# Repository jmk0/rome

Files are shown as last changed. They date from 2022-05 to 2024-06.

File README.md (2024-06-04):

# ROME
RatOS Multi Extruder

A multi extruder feeder to direct extruder solution for RatOS

## Table of Content
- [Intro](#intro)
- [Installation](#installation)
    - [Raspberry](#raspberry)
    - [Moonraker](#moonraker)
    - [RatOS](#ratos)
- [Slicer](#slicer)
    - [G-code](#G-code)
    - [Native](#native)

## Printed Parts
  - [Filament Sensor](https://github.com/HelgeKeck/rome/tree/main/cad/stl/filament_sensors)
  - [MMU Splitter](https://github.com/HelgeKeck/rome/tree/main/cad/stl/mmu_splitter)
  - [Orbiter Mounts](https://github.com/HelgeKeck/rome/tree/main/cad/stl/orbiter_mounts)

# Intro

ROME is MUCH faster then any regular MMU, ERCF or similar setups. The whole filament unloading and loading process is multiple times faster, not only because ROME just has to park the filament behind the y-junction. In its native mode, ROME handles the loading and unloading process and skips the slicer controlled part of it. This process is highly optimized for a specific Hotend / Filament combination. No more configuration of cooling moves, skinnydip, ramming, .... 

You can even set the acceleration for the wipe tower, in combination with the slicer **max speed for the wipe tower** feature, you can speed up the process even more.

With its **Ooze Ex** feature, it lets you use the most oozing hotends on the markets, it still produces a clean wipe tower

Every MM loading and unloading setting in the slicer will be deactivated and replaced with a simple unload macro. 

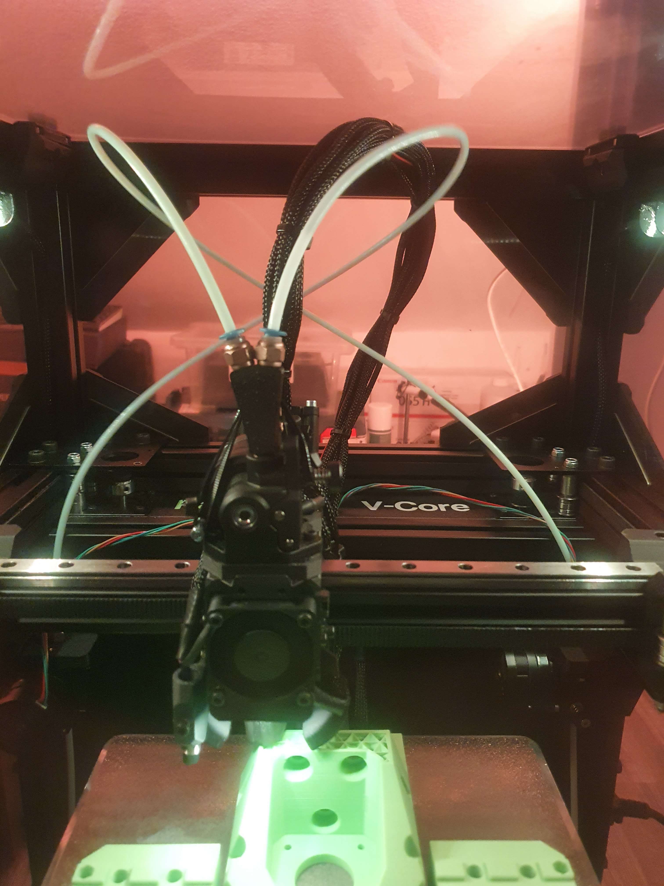
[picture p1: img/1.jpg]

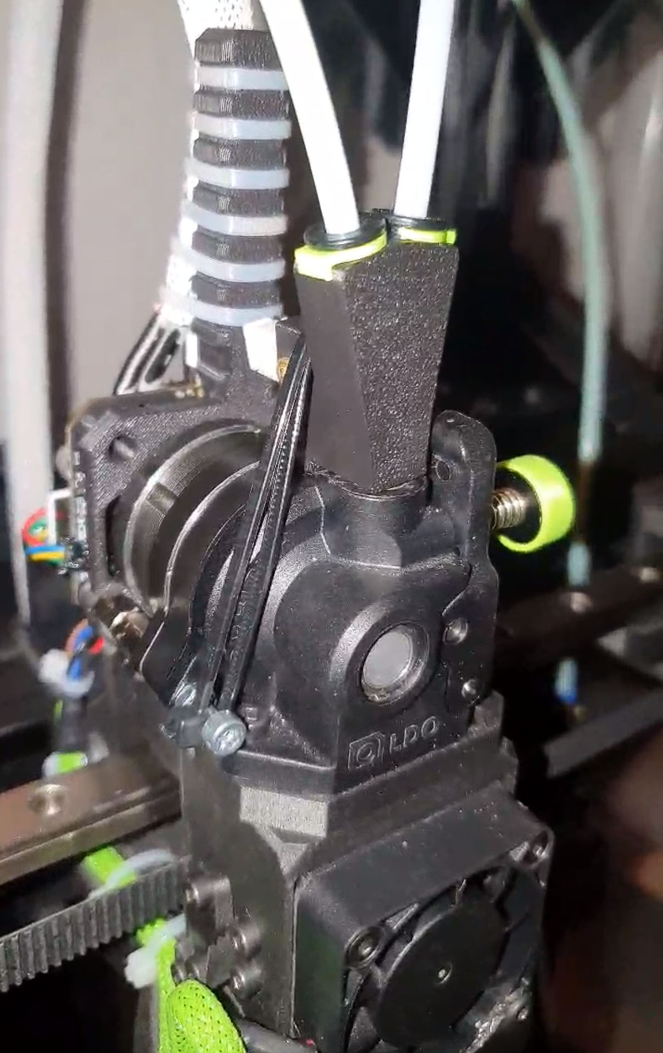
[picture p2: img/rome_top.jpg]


Wipe tower, printed with 300mm/s @ 25000 mm²/s acceleration on a Rapido UHF with Prusament PETG. 

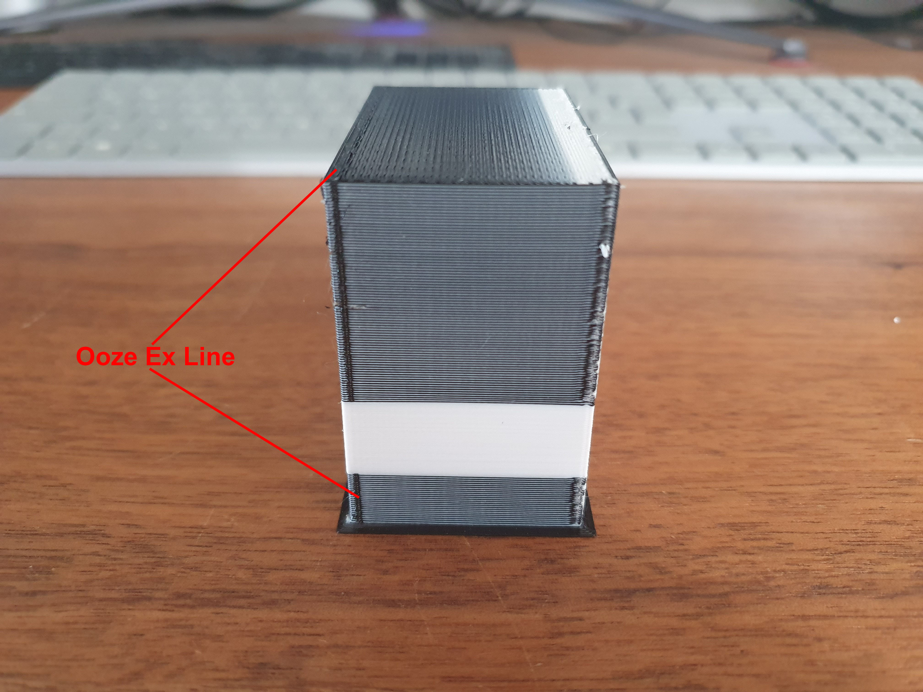
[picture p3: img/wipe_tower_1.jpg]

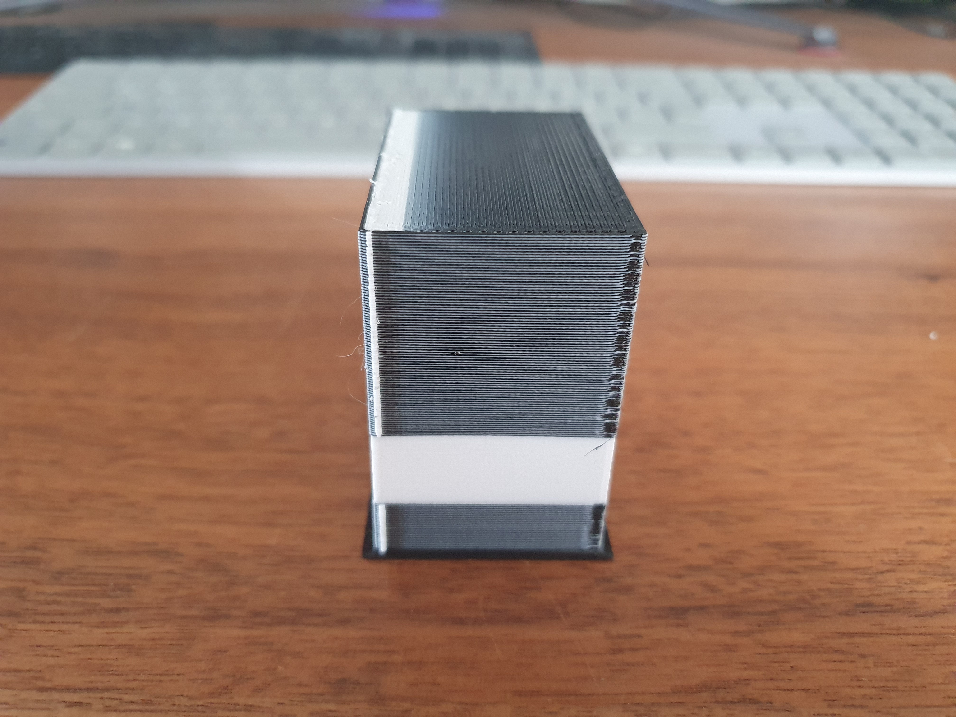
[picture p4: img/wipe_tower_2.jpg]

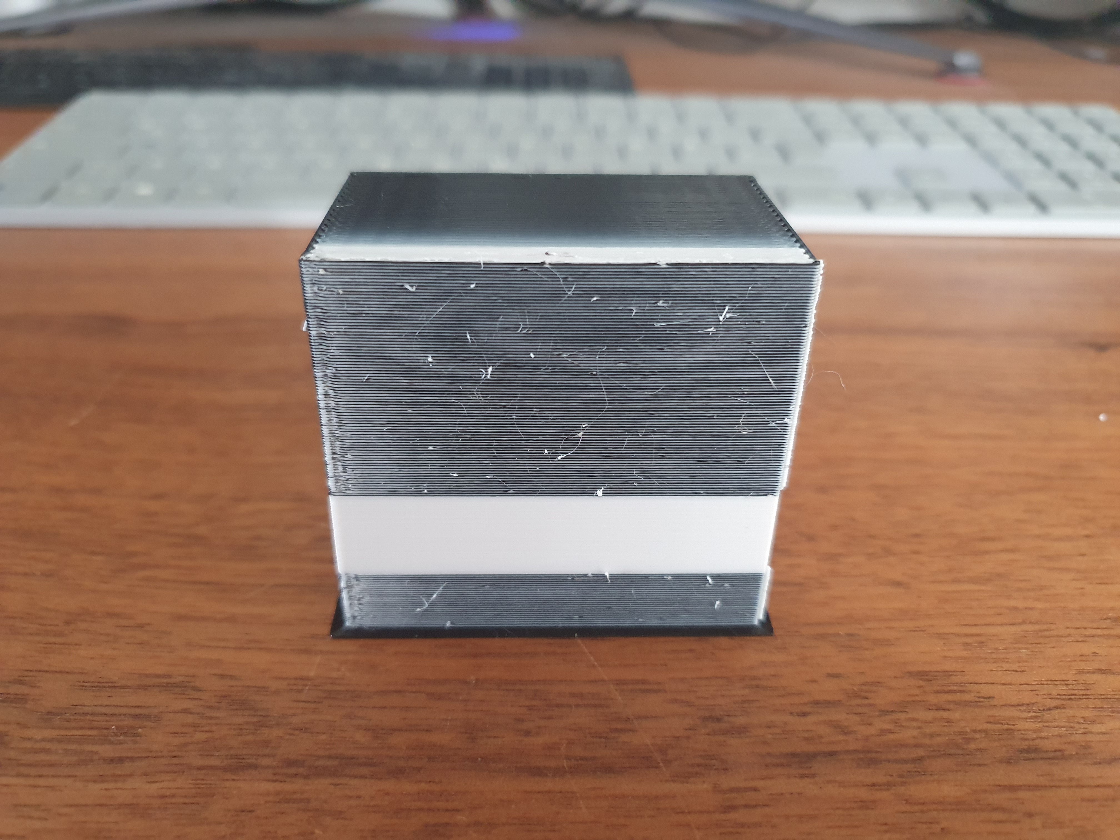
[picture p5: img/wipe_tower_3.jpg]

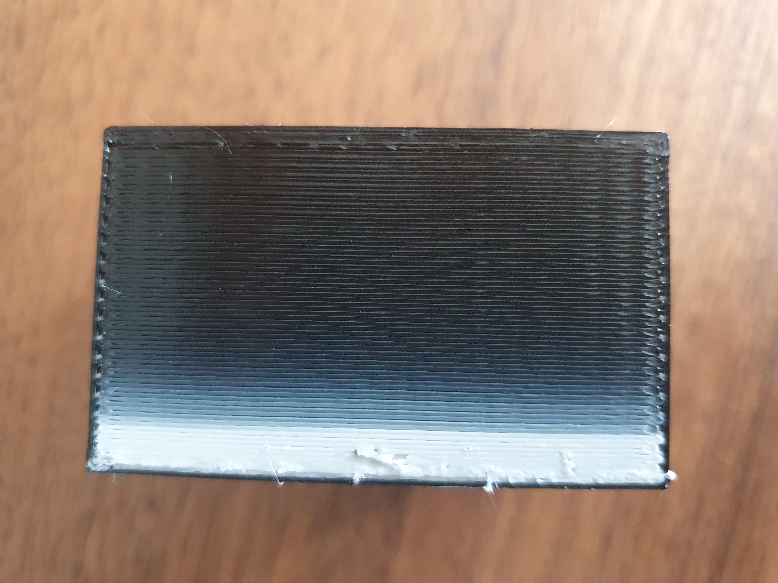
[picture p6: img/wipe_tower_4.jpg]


Examples 

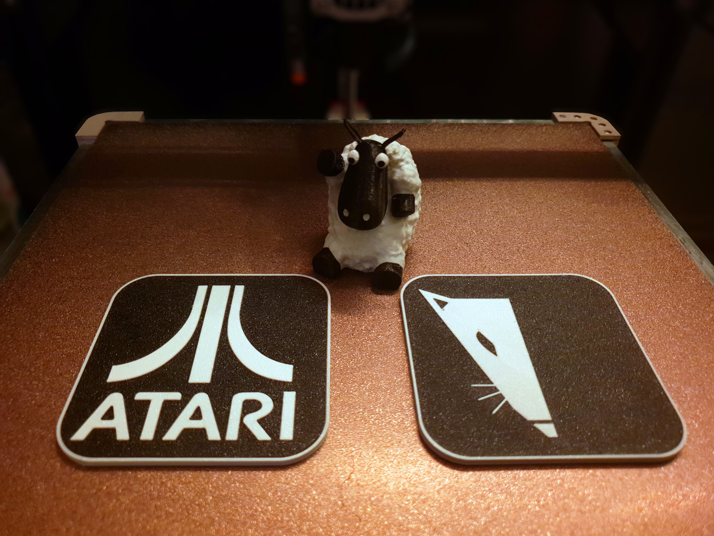
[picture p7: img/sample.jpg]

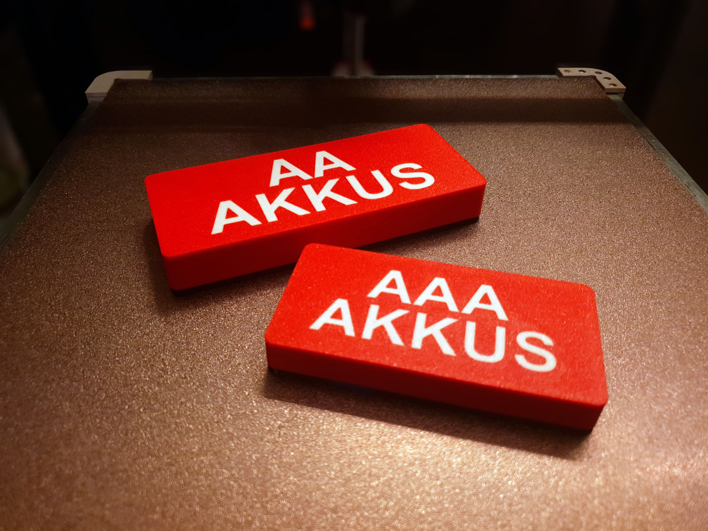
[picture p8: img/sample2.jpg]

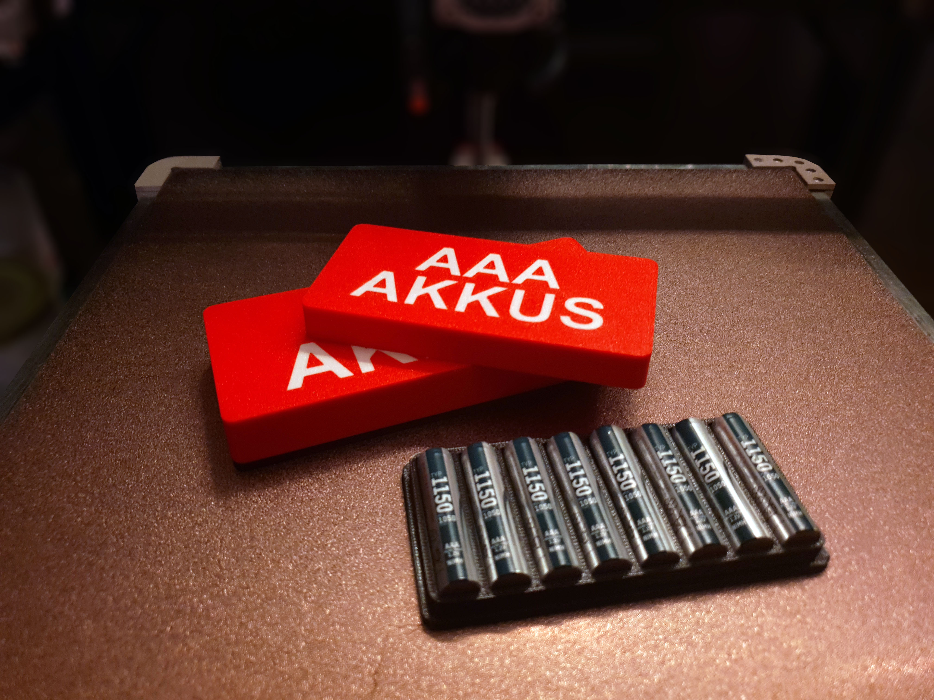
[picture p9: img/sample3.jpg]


# Installation

## Raspberry
```
cd ~/
git clone https://github.com/HelgeKeck/rome.git
bash ~/rome/install.sh
```

## RatOS

In the user overrides section in RatOS, include the base configuration file. 

```ini
[include rome.cfg]      
```

Please make all changes and overrides in this file, there is no need to do that in your printer.cfg

## Moonraker
```ini
[update_manager rome]
type: git_repo
primary_branch: main
path: ~/rome
origin: https://github.com/HelgeKeck/rome.git
is_system_service: False
managed_services: klipper
install_script: install.sh
```

# Slicer 

## G-code 

**Printer Start G-code**
```
ROME_START_PRINT EXTRUDER_TEMP=[first_layer_temperature] BED_TEMP=[first_layer_bed_temperature] CHAMBER_TEMP=[chamber_temperature] TOOL=[initial_tool] WIPE_TOWER={wipe_tower} WIPE_TOWER_X={wipe_tower_x} WIPE_TOWER_Y={wipe_tower_y} WIPE_TOWER_WIDTH={wipe_tower_width} WIPE_TOWER_ROTATION_ANGLE={wipe_tower_rotation_angle} COOLING_TUBE_RETRACTION={cooling_tube_retraction} COOLING_TUBE_LENGTH={cooling_tube_length} PARKING_POS_RETRACTION={parking_pos_retraction} EXTRA_LOADING_MOVE={extra_loading_move}
```

**Printer End G-code**
```
ROME_END_PRINT
```

**Printer Tool change G-code**
```
CHANGE_TOOL TOOL=[next_extruder]
```

**Filament Start G-code**

This is just an example, it shows how to configure pressure advance for the used extruders

```
SET_PRESSURE_ADVANCE ADVANCE=0.065 SMOOTH_TIME=0.04
SET_PRESSURE_ADVANCE ADVANCE=0.065 SMOOTH_TIME=0.04 EXTRUDER=rome_extruder_1
SET_PRESSURE_ADVANCE ADVANCE=0.065 SMOOTH_TIME=0.04 EXTRUDER=rome_extruder_2
```

## ROME Modes 

ROME can operate in two different modes, Native and Classic.

The Classic Mode works exactly like the MMU or ERCF. You are responsible to configure the Slicer like you would for the MMU or ERCF.

The Native Mode handles the filament loading and unloading on the Wipe tower. Faster filament changes, less Slicer configuration needed and more control over the process.

## Native 

**Use relative E distances**

Printer Settings->General

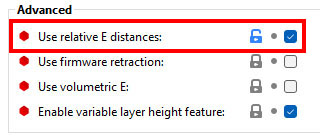
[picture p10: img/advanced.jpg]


**Activate additional extruders**

Printer Settings->General



**Dectivate all multi material parameters**

Printer Settings->Single extruder MM setup

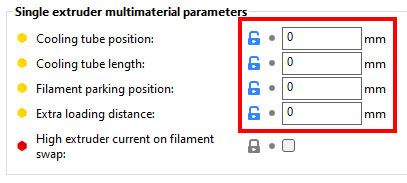
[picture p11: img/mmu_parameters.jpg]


**Dectivate advanced wiping volume**

Printer Settings->Single extruder MM setup

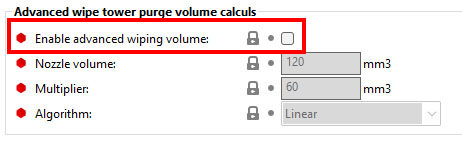
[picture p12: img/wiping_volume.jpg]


**Dectivate toolchange temperature**

Filament Settings->Multimaterial

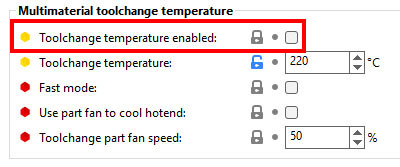
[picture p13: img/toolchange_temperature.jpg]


**Dectivate skinnydip string reduction**

Filament Settings->Multimaterial

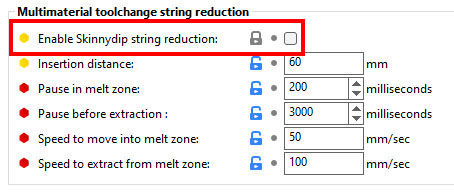
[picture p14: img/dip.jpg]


**Dectivate cooling moves and ramming**

Filament Settings->Multimaterial

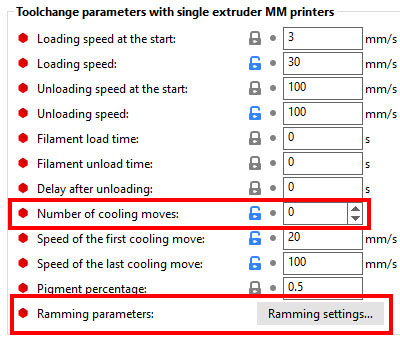
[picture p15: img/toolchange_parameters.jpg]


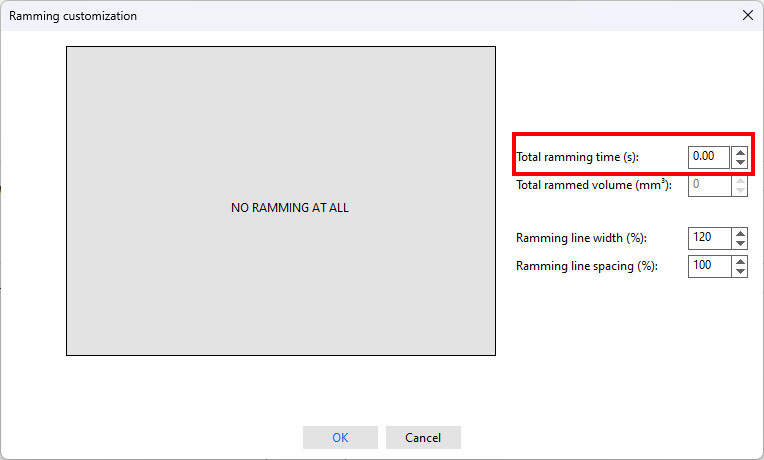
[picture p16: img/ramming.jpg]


**Enable wipe tower**

Print Settings->multiple extruders

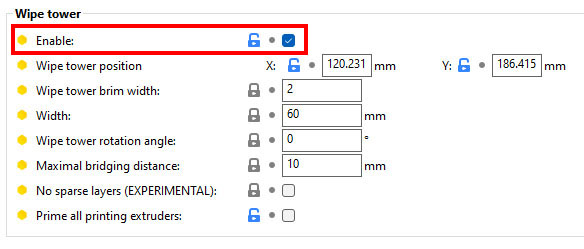
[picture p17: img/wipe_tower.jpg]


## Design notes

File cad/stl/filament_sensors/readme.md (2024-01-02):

# Filament Sensors

- [PTFE Tube Filament Sensor](https://github.com/HelgeKeck/rome/tree/main/cad/stl/filament_sensors/inline_sensor)
- [Orbiter 2.0 Y Filament Sensor](https://github.com/HelgeKeck/rome/tree/main/cad/stl/filament_sensors/orbiter_2_0_y_sensor)

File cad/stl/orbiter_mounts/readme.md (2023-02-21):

# Orbiter Mounts

## BOM
- 4 x M3 Heat Insert
- 1 x M6 PTFE fitting
- 1 x short PTFE piece between orbiter and mount
- 2 x M6x12mm screws 
- 2 x M6 3030 t-nut

## Printing
- part is already in the correct orientation

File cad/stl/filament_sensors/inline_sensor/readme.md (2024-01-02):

# PTFE Tube Filament Sensor

## BOM
- 1 x Micro Switch
- 1 x 6mm magnetic steel ball
- 1 x 5mm x 2mm N45 permanent round magnet
- 2 x M2x12mm screws 
- 2 x M2 hex nuts
- 2 x M6 PTFE fittings

## Printing
- 4 perimeter
- 0.2mm first layer height
- 0.1mm base layer height
- part is already in the correct orientation
- put the magnet via print in place in its pocket

## Post processing
- clean the filament path
- the micro switch orientation matters, make sure the lever points to the small lever pocket
- make sure the sensor is in its correct position, you can move it slightly to support more types of switches

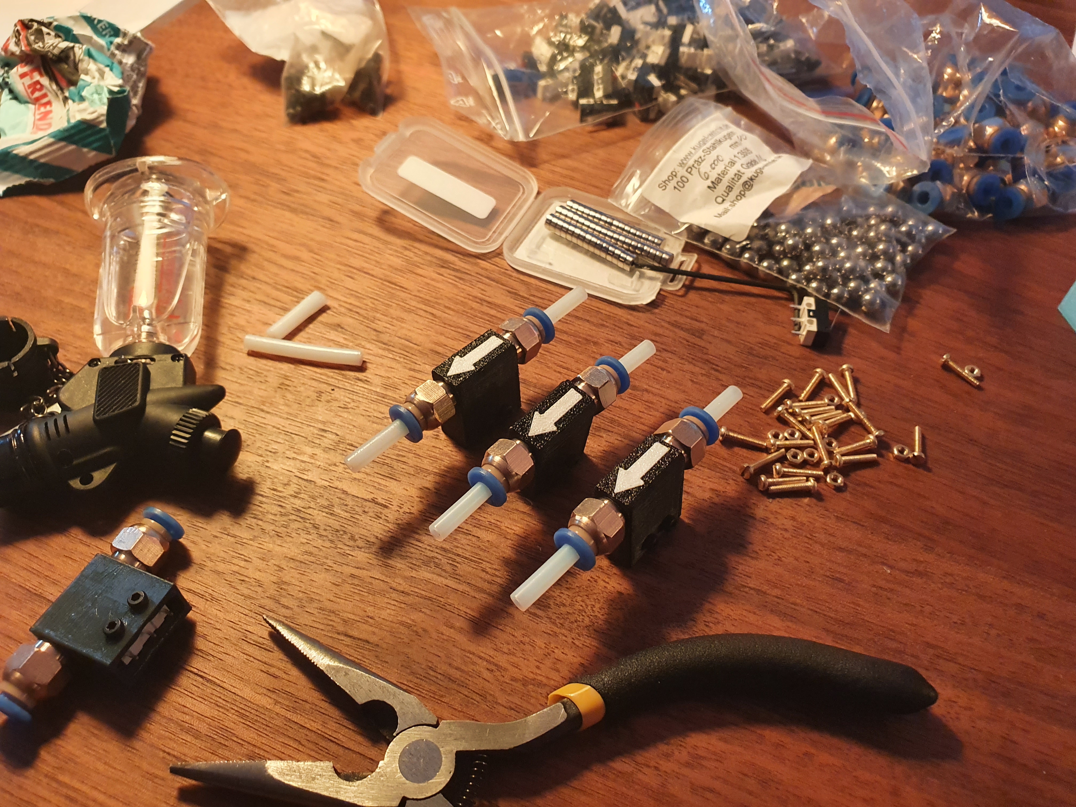
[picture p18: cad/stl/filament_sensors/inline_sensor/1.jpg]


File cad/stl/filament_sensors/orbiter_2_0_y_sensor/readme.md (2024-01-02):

# Orbiter 2.0 Y Filament Sensor

## BOM
- 1 x micro switch
- 1 x 6mm magnetic steel ball
- 1 x 5mm x 2mm N45 permanent round magnet
- 2 x M2x12mm screws 
- 2 x M2 hex nuts
- 2 x M6 PTFE fittings or 2 x collets and clips
- 1 x small PTFE tube piece between sensor and extruder

## Printing
- 4 perimeter
- 0.2mm first layer height
- 0.1mm base layer height
- generate supports
- autogenerate supports
- supports only on build plate
- part is already in the correct orientation
- put the magnet via print in place in its pocket

## Post processing
- clean the filament path
- make sure the small round adapter part is clean and fits freely into the orbiter, dont force it in 
- the micro switch orientation matters, make sure the lever points to the small lever pocket
- make sure the sensor is in its correct position, you can move it slightly to support more types of switches

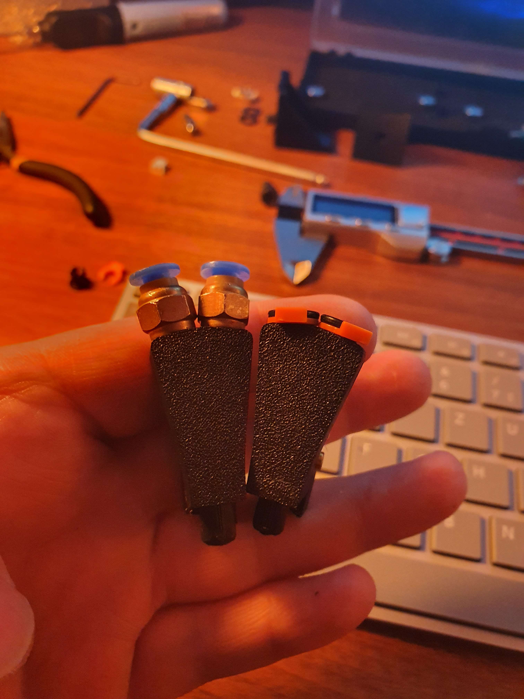
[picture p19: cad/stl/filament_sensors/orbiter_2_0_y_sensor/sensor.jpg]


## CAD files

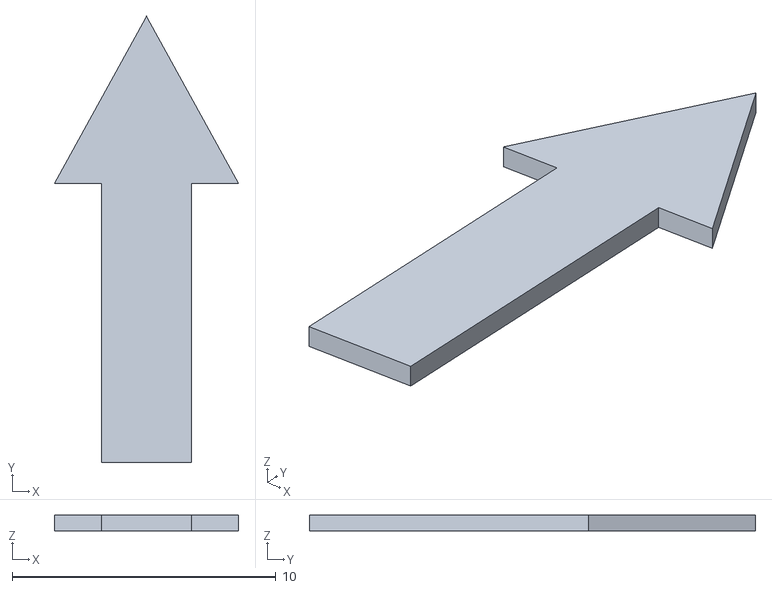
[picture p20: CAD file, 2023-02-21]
cad/stl/filament_sensors/inline_sensor/Inline Sensor Arrow.stl
6.98 x 16.9 x 0.6

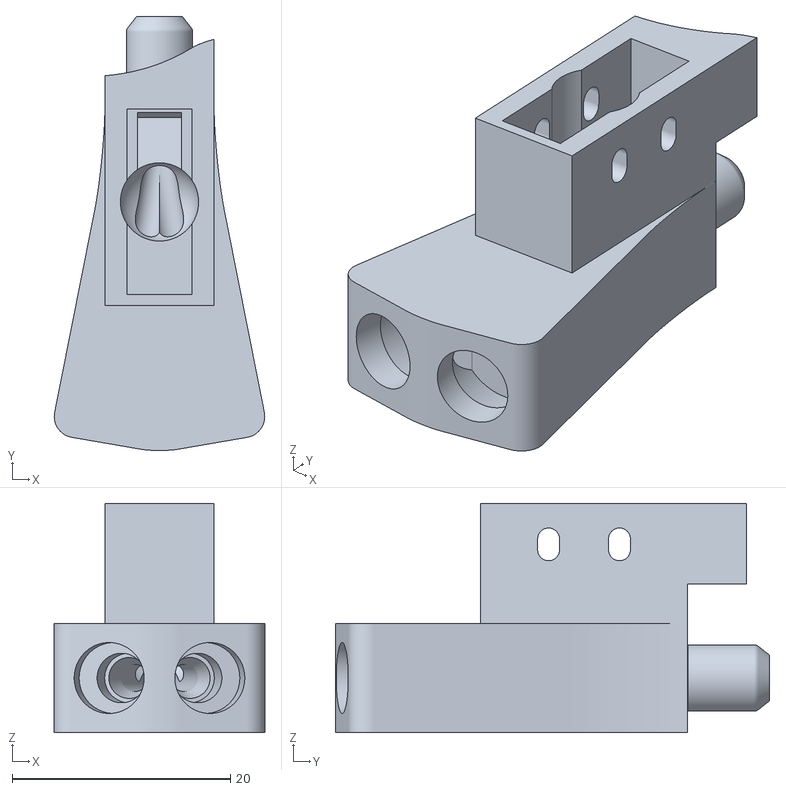
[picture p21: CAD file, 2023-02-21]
cad/stl/filament_sensors/orbiter_2_0_y_sensor/Orbiter 2.0 Y Sensor Collets.stl
19.3 x 39.8 x 21.0

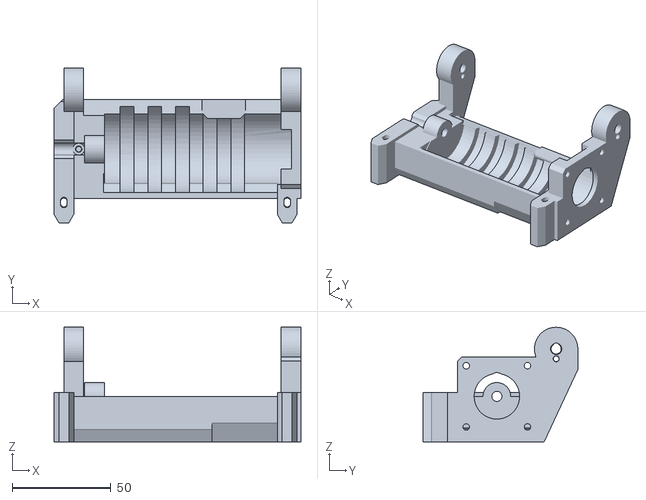
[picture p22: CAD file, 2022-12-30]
cad/stl/mmu_splitter/Idler-Body.stl
125.0 x 78.3 x 58.0

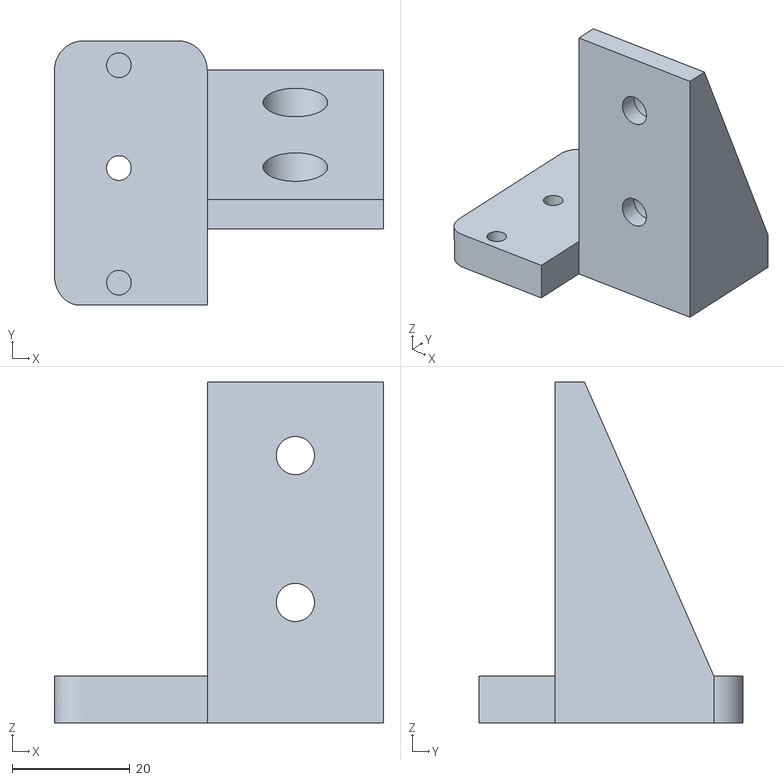
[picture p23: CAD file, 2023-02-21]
cad/stl/orbiter_mounts/orbiter_20_3030_mount.stl
56.0 x 45.0 x 58.0

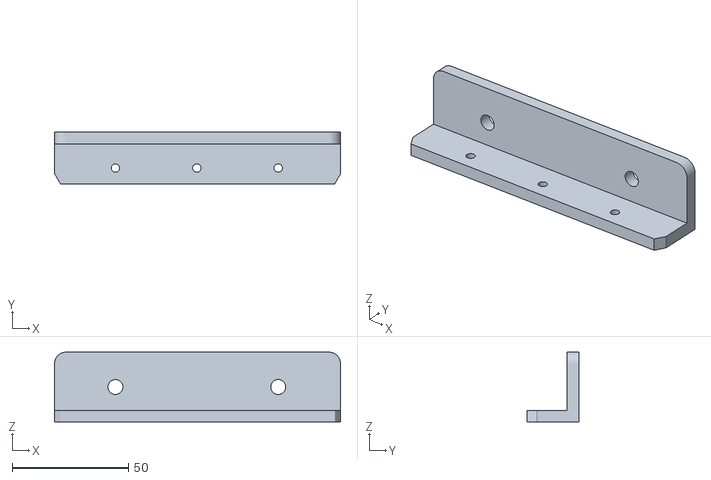
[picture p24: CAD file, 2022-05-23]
cad/stl/mmu_splitter/3030 Mount.stl
123.0 x 22.2 x 30.0

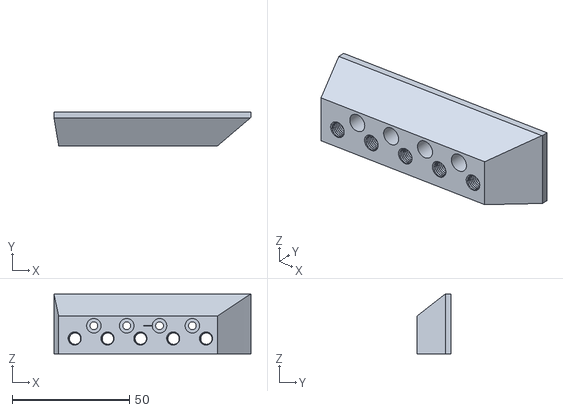
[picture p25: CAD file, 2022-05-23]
cad/stl/mmu_splitter/Front Connector 6mm.stl
84.0 x 14.6 x 25.5

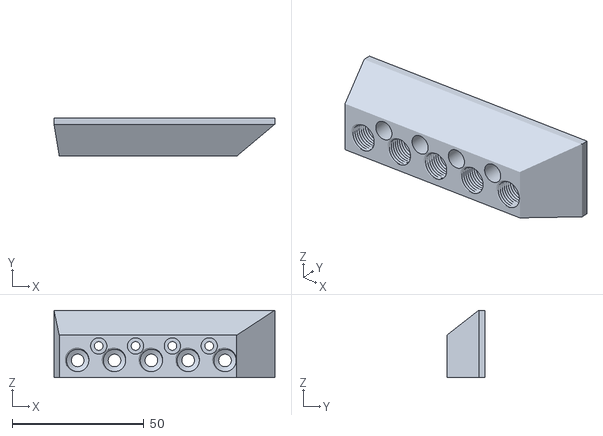
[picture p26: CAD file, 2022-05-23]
cad/stl/mmu_splitter/Front Connector 10mm.stl
84.0 x 14.6 x 25.5

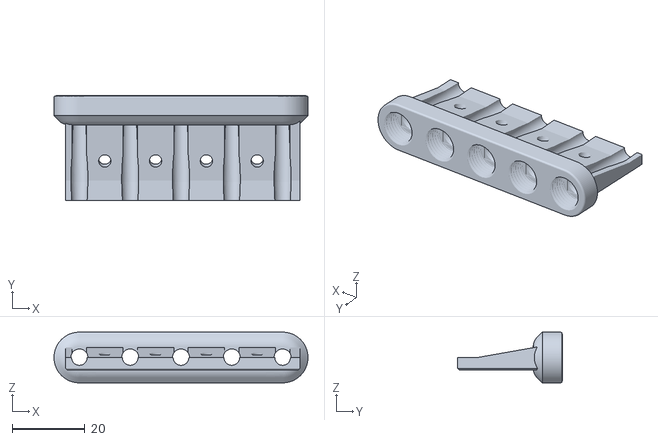
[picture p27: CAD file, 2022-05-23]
cad/stl/mmu_splitter/Back Connector 10mm.stl
70.0 x 28.8 x 14.0

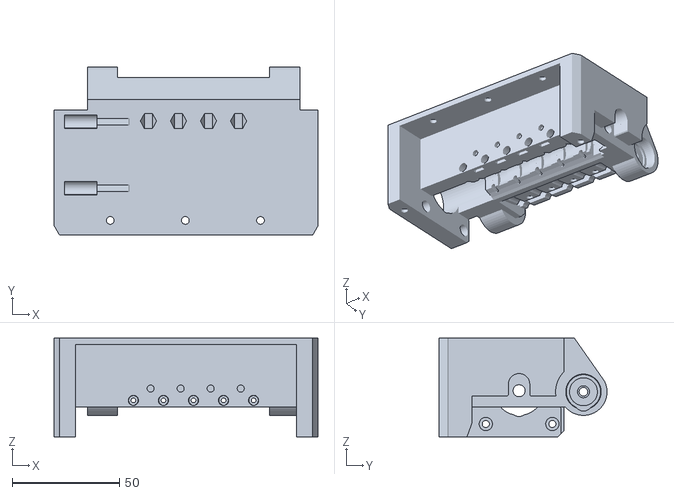
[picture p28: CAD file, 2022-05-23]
cad/stl/mmu_splitter/Pulley-Body.stl
123.0 x 78.3 x 46.0

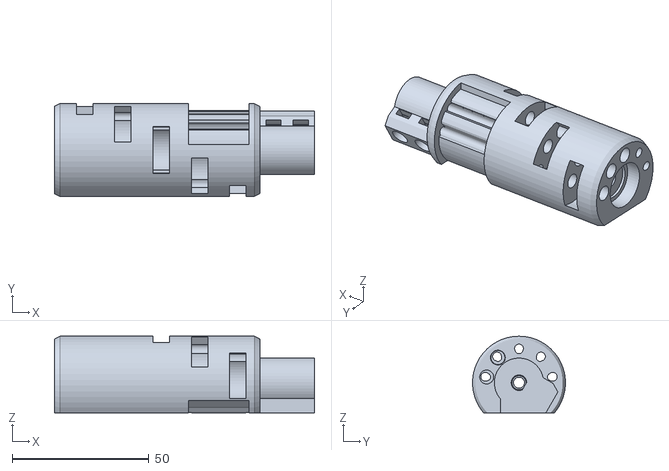
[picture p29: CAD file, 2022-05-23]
cad/stl/mmu_splitter/Idler.stl
95.0 x 33.9 x 28.0

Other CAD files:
cad/stl/orbiter_mounts/orbiter_15_3030_mount.stl

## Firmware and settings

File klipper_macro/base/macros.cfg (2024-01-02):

# ---------------------------------------------
#  Exposing macros to the UI
# ---------------------------------------------
[gcode_macro ROME_LOAD_TOOL]
variable_parameter_TOOL : 1
variable_parameter_TEMP : -1
gcode:
  LOAD_TOOL TOOL={params.TOOL|default(1)|int} TEMP={params.TEMP|default(-1)|int}


[gcode_macro ROME_UNLOAD_TOOL]
variable_parameter_TOOL : -1
variable_parameter_TEMP : -1
gcode:
  UNLOAD_TOOL TOOL={params.TOOL|default(-1)|int} TEMP={params.TEMP|default(-1)|int}


[gcode_macro ROME_SELECT_TOOL]
variable_parameter_TOOL : -1
gcode:
  SELECT_TOOL TOOL={params.TOOL|default(-1)|int}


[gcode_macro ROME_EJECT_TOOL]
variable_parameter_TOOL : -1
gcode:
  EJECT_TOOL TOOL={params.TOOL|default(-1)|int}


[gcode_macro PAUSE_ROME]
gcode:
  _PAUSE_ROME


[gcode_macro RESUME_ROME]
gcode:
  _RESUME_ROME


[gcode_macro LOAD_ALL_FILAMENTS]
gcode:
  LOAD_FILAMENTS


[gcode_macro SET_INFINITE_SPOOL]
gcode:
  _SET_INFINITE_SPOOL


# ---------------------------------------------
#  RatOS integration
# ---------------------------------------------
[gcode_macro _START_PRINT_AFTER_HEATING_EXTRUDER]
variable_tool: -1
gcode:
  {% if tool >= 0 %}
    LOAD_TOOL TOOL={tool} SENSOR=1 TEMP=-1
  {% endif %}
  {% if printer["gcode_macro RatOS"].nozzle_priming|lower == 'primeline' %}
    PRIME_LINE
  {% endif %}
  {% if printer["gcode_macro RatOS"].nozzle_priming|lower == 'primeblob' %}
    PRIME_BLOB
  {% endif %}
  {% if printer["gcode_macro RatOS"].skew_profile is defined %}
    SKEW_PROFILE LOAD={printer["gcode_macro RatOS"].skew_profile}
  {% endif %}


# ---------------------------------------------
#  Pause / Resume
# ---------------------------------------------
[gcode_macro _PAUSE_ROME]
gcode:
  SAVE_GCODE_STATE NAME=PAUSE_state
  #SET_IDLE_TIMEOUT TIMEOUT=36000
  G91
  G1 Z+50 F3000
  G90
  {printer.configfile.settings['gcode_macro pause'].rename_existing}


[gcode_macro _RESUME_ROME]
gcode:
  RESTORE_GCODE_STATE NAME=PAUSE_state MOVE=1 SPEED=600
  {printer.configfile.settings['gcode_macro resume'].rename_existing}

# -------------------------------------										
# Extruder Notifications
# -------------------------------------										
[gcode_macro _UNLOAD_EXTRUDER]
gcode:
  M118 unloading extruder {params.EXTRUDER} 
  # put your custom gcode here 
  # in case you you want to control some status LEDs 

[gcode_macro _SELECT_EXTRUDER]
gcode:
  M118 selecting extruder {params.EXTRUDER} 
  # put your custom gcode here 
  # in case you you want to control some status LEDs 

[gcode_macro _EXTRUDER_SELECTED]
gcode:
  M118 Extruder {params.EXTRUDER} selected
  # put your custom gcode here 
  # in case you you want to control some status LEDs 

[gcode_macro _EXTRUDER_ERROR]
gcode:
  M118 Extruder {params.EXTRUDER} error
  # put your custom gcode here 
  # in case you you want to control some status LEDs 

[gcode_macro _CONTINUE_PRINTING]
gcode:
  M118 Continue printing with extruder {params.EXTRUDER}
  # put your custom gcode here 
  # in case you you want to control some status LEDs 


# -------------------------------------										
# Auto loader 
# -------------------------------------										
[gcode_macro _AUTOLOAD_RESUME_AFTER_INSERT]
gcode:
  M118 Filament {params.TOOL} inserted
  # put your custom gcode here 
  # in case you have a nozzle wiper or a similar solution 
  RESUME 

[gcode_macro _FEEDER_RUNOUT_RESUME_AFTER_SWAP]
gcode:
  M118 Spool replaced with Filament {params.TOOL}
  # put your custom gcode here 
  # in case you have a nozzle wiper or a similar solution 
  RESUME 


[gcode_macro FILAMENT_RUNOUT]
gcode:
  M118 Filament {params.TOOL} ran out
  RESUME 

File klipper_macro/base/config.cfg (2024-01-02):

# -------------------------------------										
#  ROME CONFIGURATION
# -------------------------------------										
[rome]
heater_timeout: 6000                            # Heater Timeout in case of rome paused the print

unload_filament_after_print: 1                  # 1 = unloads filament after printing has finished
                                                # 0 = filament stays in hotend

wipe_tower_acceleration: 5000                   # printer acceleration when printing the wipe tower

use_feeder_runout_detection: 0                  # 1 = on
                                                # 0 = off 

use_ooze_ex: 1                                  # 1 = rome distributes oozed material over the length of the wipe tower
                                                # 0 = try your luck 

use_filament_caching: 1                         # 1 = rome caches the filament right behind the toolhead sensor instead of completely unloading it
                                                # 0 = no caching

extruder_push_and_pull_test: 1                  # 1 = test if filament could successfully loaded into extruder
                                                # 0 = do not test

#filament_groups: 1:2,4:5                        # filament cache configuration, this tells rome which filament arrives in which bowden tube to the hotend

nozzle_loading_speed_mms: 10                    # extruder speed when moving the filament between the parking position and the nozzle 
filament_homing_speed_mms: 50                   # extruder speed when moving the filament inside bowden tube
filament_parking_speed_mms: 50                  # extruder speed when moving the filament between the filament sensor and the parking position

parking_position_to_nozzle_mm: 50               # distance between the parking position and the nozzle
toolhead_sensor_to_bowden_cache_mm: 75          # distance between the filament sensor and the filament caching position
toolhead_sensor_to_bowden_parking_mm: 500       # distance between the filament sensor and the filament parking position
extruder_gear_to_parking_position_mm: 40        # distance between the extruder gears and the parking position
toolhead_sensor_to_extruder_gear_mm: 15         # distance between the filament sensor and the extruder gears

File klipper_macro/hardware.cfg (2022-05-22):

# -------------------------------------										
# Filament Sensor
# -------------------------------------										
[filament_switch_sensor toolhead_filament_sensor]
pause_on_runout: False
event_delay: 0.1
pause_delay: 0.1
switch_pin: ^!PG15
insert_gcode:
  ROME_INSERT_GCODE
runout_gcode:
  ROME_RUNOUT_GCODE

# -------------------------------------										
# Extruder 
# Orbiter 1004
# -------------------------------------										
[extruder]
max_extrude_only_velocity: 100
max_extrude_only_accel: 1000
max_extrude_only_distance: 400
max_extrude_cross_section: 999999

[tmc2209 extruder]
run_current: 0.85

# -------------------------------------										
# Rome Extruder 1
# Orbiter 1004
# -------------------------------------										
[extruder_stepper rome_extruder_1]
extruder:
step_pin: PG4
dir_pin: !PC1
enable_pin: !PA0
microsteps: 64
rotation_distance: 4.63
full_steps_per_rotation: 200

[tmc2209 extruder_stepper rome_extruder_1]
uart_pin: PC7
run_current: 0.85
stealthchop_threshold: 0
interpolate: False
driver_TBL: 1
driver_TOFF: 3
driver_HEND: 9
driver_HSTRT: 7

# -------------------------------------										
# Rome Extruder 2
# Orbiter 1004
# -------------------------------------										
[extruder_stepper rome_extruder_2]
extruder:
step_pin: PF9
dir_pin: !PF10
enable_pin: !PG2
microsteps: 64
rotation_distance: 4.63
full_steps_per_rotation: 200

[tmc2209 extruder_stepper rome_extruder_2]
uart_pin: PF2
run_current: 0.85
stealthchop_threshold: 0
interpolate: False
driver_TBL: 1
driver_TOFF: 3
driver_HEND: 9
driver_HSTRT: 7

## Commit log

2022-05-10 extruder config added
    [ERCF_FORM_TIP_STANDALONE.cfg, config.cfg, hardware.cfg]
2022-05-10 extruder syncing added
    [config.cfg, hardware.cfg]
2022-05-13 wokring update
    [config.cfg, macros.cfg]
2022-05-18 clean up
    [config.cfg, hardware.cfg]
2022-05-22 M84 added after unload after print
2022-05-22 better ratos integration
    [macros.cfg]
2022-05-22 unlimited extruders
    [config.cfg, macros.cfg]
2022-05-23 mmu splitter
    [MMU Back Connector.stl, MMU Bottom.stl, MMU Front Adapter.stl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]
2022-05-23 mmu stl update
    [3030 Mount.stl, Back Connector 10mm.stl, Front Connector 10mm.stl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]
2022-05-23 heater error fixed
2022-05-25 config changes
    [config.cfg, extruder.cfg, extruder_feeder.cfg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]
2022-09-19 notifications added
    [macros.cfg]
2022-12-03 chamber temp control added
    [base.cfg]
2022-12-09 new sensors
    [Big Connector.stl, Left Arm.stl, Left Orbiter Mount.stl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]
2022-12-11 doc updated
    [config.cfg, extruder_feeder.cfg, mmu_splitter.cfg]
2023-02-21 sensors updated
    [Inline Sensor Arrow.stl, Orbiter 2.0 Y Sensor Collets.stl, Y Junction Collets.stl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]
2023-02-21 orbiter mount
    [orbiter_15_3030_mount.stl, orbiter_20_3030_mount.stl]
2023-02-21 Update Orbiter 1.5 Sensor Fitting.stl
2023-02-23 infinite spool feature
    [macros.cfg]
2023-02-23 infinite spool
    [macros.cfg]
2023-02-24 new event added
    [macros.cfg]
2024-01-26 missing parameter to f_filament_sensor_triggered added
    [rome.py]
